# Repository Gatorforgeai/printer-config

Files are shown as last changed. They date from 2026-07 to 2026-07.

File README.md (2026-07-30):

# printer-config

Version control and restore point for the CR-10 Max and Ender-3 Pro Cura configuration.

## What is here

| Path | What |
|---|---|
| `PRINTER-SETTINGS-MASTER-TABLE.md` | Copy of the master settings table. **The live copy lives in the vault** at `_AI_OBS\02 Projects\AI CAD 3D Print Laser\_PRINTER SETTINGS MASTER TABLE.md` |
| `cura-5.13/quality_changes/` | All custom print profiles (both machines, all materials) |
| `cura-5.13/definition_changes/` | Machine-level settings, including the start G-code carrying `M92 E415` |
| `cura-5.13/user/` | Live GUI overrides. These sit ABOVE quality_changes in the container stack and beat everything else |
| `cura-5.13/variants/` | Nozzle variants, if any |

## Why this repo exists outside the vault

The Obsidian vault is at `D:\Google Drive\_AI_OBS`, which is inside Google Drive. Drive syncs
`.git` internals mid-write and can corrupt the object store, so the vault is deliberately **not**
a git repo. This repo lives on local disk instead.

## Restoring a profile

Cura must be **closed** - it rewrites its config on exit and will clobber anything restored
while it is running.

```
copy "cura-5.13\quality_changes\<file>" "%APPDATA%\cura\5.13\quality_changes\"
```

## Refreshing this repo after a settings change

The master table is generated from these files, not typed by hand. After changing settings:

1. Close Cura.
2. Re-copy `%APPDATA%\cura\5.13\{quality_changes,definition_changes,user}\*.inst.cfg` here.
3. Regenerate the table and diff - the diff shows exactly which settings moved.

## Gotchas worth knowing before editing anything in here

- **Scope matters.** A setting whose `settable_per_mesh` and `settable_per_extruder` are BOTH
  false in `fdmprinter.def.json` is GLOBAL and belongs in `creality_<machine>_<name>.inst.cfg`.
  Written into the extruder file it is **silently ignored** - no error. `retraction_combing` and
  `layer_height_0` are both global.
- **Filename encoding differs by folder.** `quality_changes` uses `_%23N`; `extruders` and `user`
  use `+%23N`. Mixing them creates duplicate profiles rather than replacing.
- **`quality_type` filtering.** A profile only appears in Cura if its `quality_type` exists for the
  current nozzle + material. The Ender's 0.8 nozzle offers **only `draft`**, which is why
  `CE3PRO TPU` and `CE3PRO NYLON` (both `standard`) have never been selectable.

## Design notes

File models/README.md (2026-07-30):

# Moved — do not edit here

`mineral_tray.py` lived here briefly on 2026-07-30. It is now its own project:

**`D:\GatorForge\AI CAD 3D Print Laser\Mineral Tray`** — generator, STLs, `SPEC.md`, `AGENTS.md`.

It was moved because this repo is the **Cura configuration backup**, not a home for models, and
because two copies of a generator is a fork with a delay fuse. Nothing here is authoritative.

Register: **Mineral Tray**, parent *AI CAD 3D Print Laser*.

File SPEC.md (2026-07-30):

# SPEC — Printer Config

Status: DRAFT — not yet ratified
Ratified: <date, by Mark>

> ⚠️ Written after the work, not before it. This project grew out of a calibration session rather
> than an interview, so read it as a transcription of what was actually built and check it, rather
> than a contract agreed up front.

---

## WHY

Printer settings were spread across three documents that disagreed with each other, and the Cura
profiles themselves existed as a single unversioned copy under `%APPDATA%`. A Cura upgrade, a bad
edit, or a disk event meant re-tuning both machines from nothing. Separately, a week of failed
prints was traced to an e-step value nobody had ever recorded — the settings were undocumented in
exactly the places that mattered.

If never built: every calibration is repeated from scratch after each mishap, and no value is
traceable to the measurement that produced it.

## WHAT

One generated table that is the single source of truth for every Cura setting on both printers,
version control and offsite backup of the underlying `.inst.cfg` files, the calibration instruments
that produce the numbers, and the recorded reasoning behind each value.

**Success artifact:** `refresh.py` runs, the table regenerates from disk, the verifier reports zero
mismatches across every value, and a commit lands on the remote. If the feature were dead the
verifier would report a nonzero count or refuse on zero values compared.

**Explicitly NOT:** a slicer replacement, a profile-authoring GUI, or a general 3D-printing wiki.
It documents these two machines and nothing else.

## WHO

Mark, and any AI session resuming printer work. Triggered by hand after tuning — nothing schedules
it.

## WHERE

Repo `D:\GatorForge\AI CAD 3D Print Laser\Printer Config`, GitHub remote `Gatorforgeai/printer-config`.
Live table in the vault at
`_AI_OBS\02 Projects\AI CAD 3D Print Laser\Printer Config\_PRINTER SETTINGS MASTER TABLE.md`.
Backup at `_AI_OBS\10 Attachments\printer-config-backup\`.

Reads `%APPDATA%\cura\5.13\` — **SACRED, never written to by this project.**

## WHEN

On demand, after any settings change. A run takes well under a minute.

## HOW

`refresh.py` copies live Cura config into the repo and the Drive backup, regenerates the table
between markers in the vault document, verifies it against disk, then commits and pushes.

Riskiest part: it must refuse to run while Cura is open, because Cura rewrites its config on exit
and would silently capture a stale snapshot.

## CONSTRAINTS

- Cura must be closed; the tool aborts otherwise.
- Never write into `%APPDATA%\cura` — read-only from this project's perspective.
- Git internals must stay out of Google Drive (Drive corrupts a live object store); the working
  repo is on local disk and only a finished bundle goes to Drive.
- No hard deletes; removals go to a dated quarantine and the Removal Log.
- Prices, where hardware is discussed, are live-data-only.

## VERIFICATION

```
python refresh.py
```

Expected: `values compared: <N> | errors: 0`, a new commit, `pushed`. The verifier refuses to pass
on zero values compared, so an empty or broken parse cannot masquerade as success.

---

## Components

- `refresh.py` — orchestrator: capture, regenerate, verify, commit, push
- `tools\generate_table.py` — emits the table between markers; exits nonzero on an uncategorised
  setting or a missing profile rather than silently omitting it
- `tools\verify_table.py` — independent check of table against `.inst.cfg`; catches hand edits
- `calibration\` — flow-cal cylinder + generator; the superseded plain cube kept as history
- `cura-5.13\` — the versioned profile copies

## Open decisions

Tracked in the vault ledger:
`_AI_OBS\02 Projects\AI CAD 3D Print Laser\Printer Config\02 Next Actions.md`

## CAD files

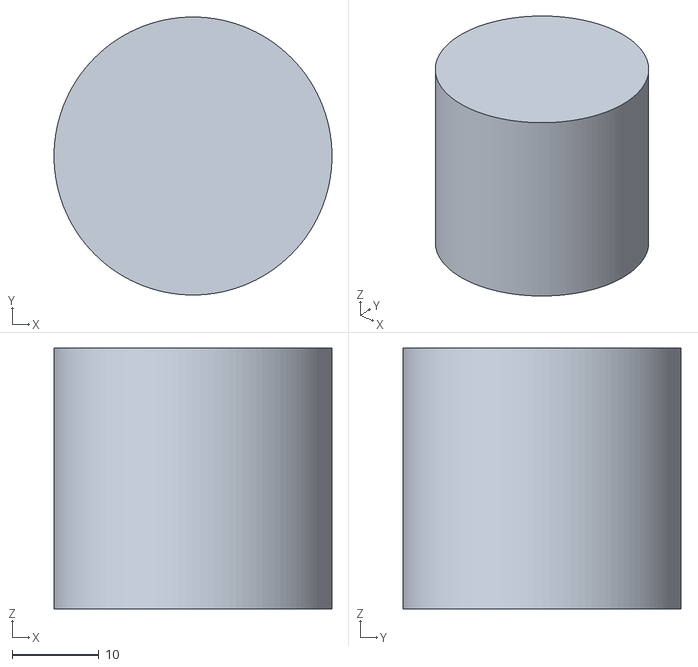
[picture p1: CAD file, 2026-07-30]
calibration/cyl32.stl
32.0 x 32.0 x 30.0

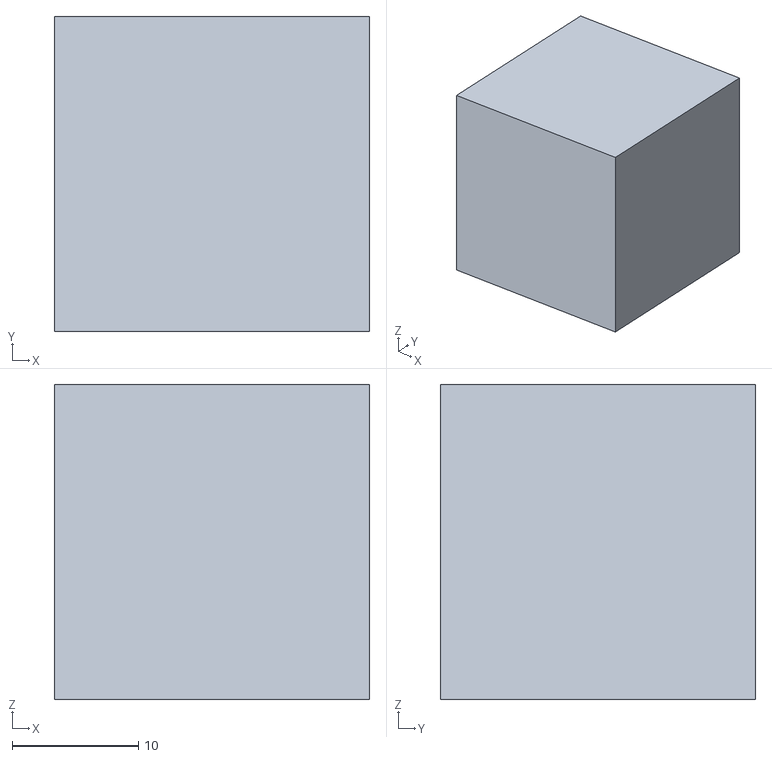
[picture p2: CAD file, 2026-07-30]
calibration/cube25.stl
25.0 x 25.0 x 25.0

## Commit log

2026-07-30 Initial commit: printer settings master table + Cura 5.13 profile backup
    Master table is generated from the .inst.cfg files, not hand-transcribed:
    174 values across 45 settings x 8 profiles, verified 0 mismatches against disk.
    Captures the 2026-07-29 CR-10 Max tuning state: flow 93.6 (measured 94.1,
    0.5% operator reduction on top), material_flow_layer_0 back to 100,
    top_bottom_thickness 1.2, skin_monotonic, ironing, retraction_combing
    no_outer_surfaces (global), layer_height_0 0.28, bed 55/60.
    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
2026-07-30 Add parametric micromineral tray generator
    34.5mm square boxes, 3mm dividers (hinge/clasp interlock clearance),
    X-rib open floors, gusseted corner lift fins.
    Fins are fins not posts: 4x25mm section instead of 4x4mm. Square posts
    would snap at the layer boundary under a loaded tray, and 133 layers of
    four tiny towers trips Cura's minimum-layer-time throttle for ~22min of
    nozzle dwell.
    Fin height 52mm not 40mm: boxes are 36mm on a 2mm floor, so 40mm leaves
    2mm of grip.
2026-07-30 Retarget paths: repo moved under AI CAD 3D Print Laser, vault table moved into Printer Config subproject
2026-07-30 Version the flow-test cube - it existed only in Downloads
    Plain 25mm cube, 12 triangles, no embossed lettering. The standard XYZ
    calibration cube is unusable in vase mode: its raised letters break the
    single closed contour spiralize requires.
    This is the measuring instrument for flow calibration on both machines and
    both machine profiles cite it. It was living in one unversioned copy in
    Downloads.
    [flow_test_cube_25mm_plain.stl]
2026-07-30 Add flow-calibration cylinder + generator
    A cube forces the nozzle to decelerate into every corner, and extrusion
    width tracks speed - so wall thickness varies around the part and the
    measurement depends on where the calipers land. A cylinder holds constant
    speed the whole way round.
    32mm diameter gives a 100.5mm perimeter, matched to the old 25mm cube's
    100mm so layer times and print times stay comparable. 30mm tall so the
    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
    [flow_cal_cylinder_32x30.stl]
2026-07-30 Conform to Project Scaffold v2 (ADR-2026-07-30)
    Adds SPEC.md (awaiting ratification), AGENTS.md, .gitignore from the ratified
    template. Vault kit created: Project Note.md, 02 Next Actions.md, Build Notes.md.
    Removes the repo copy of the master settings table. A copy of a vault file
    carries front matter, but repo files must carry none, and stripping it would
    diverge from the original - a file that cannot satisfy both rules should not
    exist. It was also a fork of the declared source of truth. refresh.py no
    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
2026-07-30 Shorten calibration STL filenames for printer SD limit
    flow_cal_cylinder_32x30 -> cyl32, flow_test_cube_25mm_plain -> cube25.
    Generator retargeted so a re-run does not undo it.
    [cube25.stl, cyl32.stl]
